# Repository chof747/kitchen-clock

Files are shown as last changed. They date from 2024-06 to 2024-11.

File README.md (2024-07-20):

# Kitchen Clock Project

This project is building a kitchen glock with the following functions:

- Servo driven largely visible glock gauge
- Alarm functions that can be sequenced easily
- Temperature control of a stove or oven
- Integration into home automation systems with HA and/or MQTT
- Ringing alarm function

the project will contain all the necessary electrical and housing components.

## PCB

**v1.0**: Initial version of PCB sent to production on 22.07.2024

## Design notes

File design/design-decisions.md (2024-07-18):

# Design Decisions for Kitchen Clock

## Using USB CDC Mode to upload firmware

I decided to skip the standard ESP serial programmer and use USB JTAG/CDC mode for programming and communicating with the microcontroller on board. 

A breakout of RX/TX, GPIO0 and GND is still provded as a fallback if USB does not work.

Programming the firmware can work as described here:
[USB Settings for Logging with the ESP32-S3 in PlatformIO](https://thingpulse.com/usb-settings-for-logging-with-the-esp32-s3-in-platformio/)

**Note:** It can be possible to put the ESP32 into boot mode before it is able to be programmed. I decided not to add a specified Boot button on the board but one can use the breakout of RX/TX/GPI0 instead

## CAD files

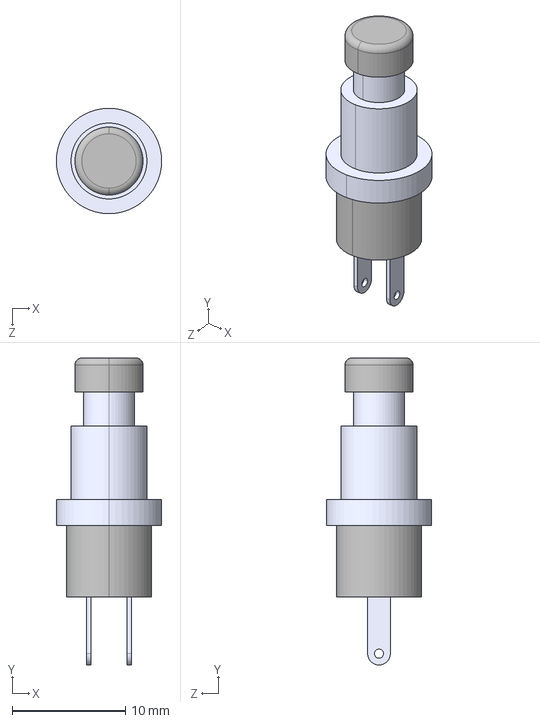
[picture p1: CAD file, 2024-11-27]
3dmodel/resources/button.STEP
9.30 x 27.1 x 9.30 mm

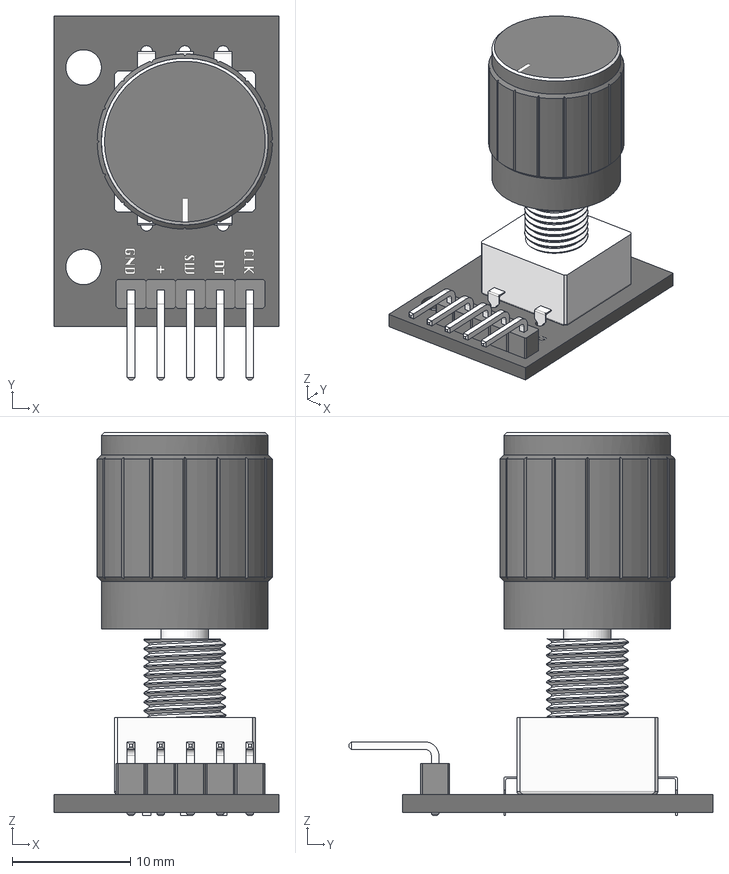
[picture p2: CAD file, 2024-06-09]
3dmodel/resources/Rotary Encoder - KY-040.step
19.0 x 30.8 x 32.4 mm

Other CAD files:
3dmodel/assemblies/clock-assembly.FCStd
3dmodel/assemblies/component-assembly.FCStd
3dmodel/components/base.FCStd
3dmodel/parameter.FCStd
3dmodel/components/socket.FCStd
3dmodel/assemblies/controls.FCStd
3dmodel/components/dial.FCStd
3dmodel/assemblies/base-pcb.FCStd
3dmodel/components/front.FCStd
3dmodel/components/rot-enc-knob.FCStd
3dmodel/components/tftdisplay.FCStd
3dmodel/components/servo-horn.FCStd
3dmodel/components/scafold.FCStd
3dmodel/components/button.FCStd
3dmodel/components/gauge.FCStd
3dmodel/components/pcb.FCStd
3dmodel/components/1.8_inches_128x160_RGB_TFT_LCD v3.step
3dmodel/components/display-bracket.FCStd
3dmodel/components/knob.FCStd
3dmodel/resources/M7 × 0.75 NUT.STEP

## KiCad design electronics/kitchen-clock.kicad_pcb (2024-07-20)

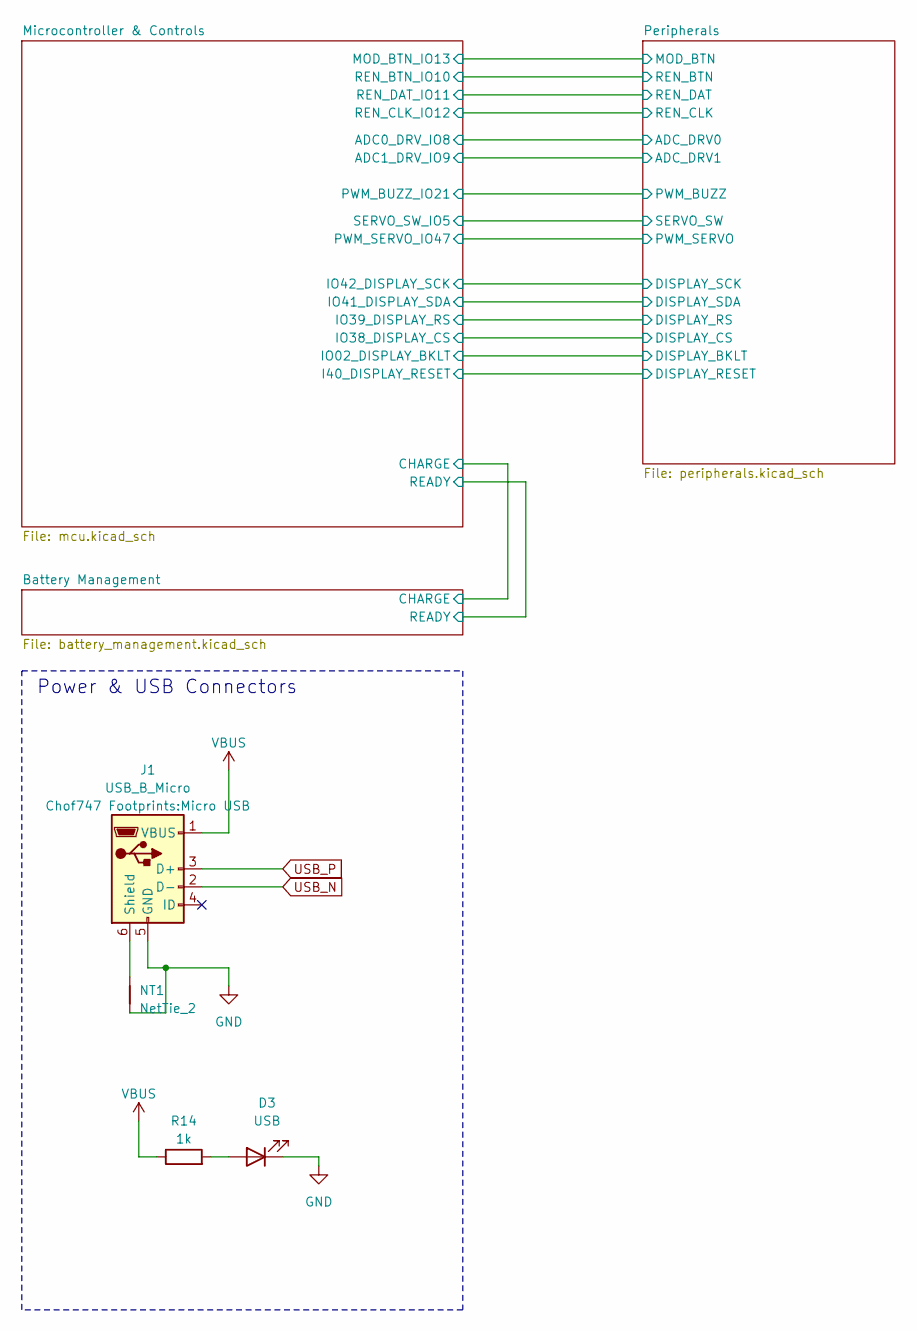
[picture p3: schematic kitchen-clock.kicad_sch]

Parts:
D3: USB; LED_0603_1608Metric_Pad1.05x0.95mm_HandSolder
J1: USB_B_Micro; Micro USB
NT1: NetTie_2; NetTie-2_SMD_Pad0.5mm
R14: 1k; R_0603_1608Metric_Pad0.98x0.95mm_HandSolder

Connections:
GND: D3.1 (K), J1.5 (GND), NT1.1; also elsewhere on the board
unnamed: D3.2 (A), R14.2
unnamed: J1.6 (Shield), NT1.2
USB_N: J1.2 (D-); also elsewhere on the board
USB_P: J1.3 (D+); also elsewhere on the board
VBUS: J1.1 (VBUS), R14.1; also elsewhere on the board

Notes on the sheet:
Power & USB Connectors

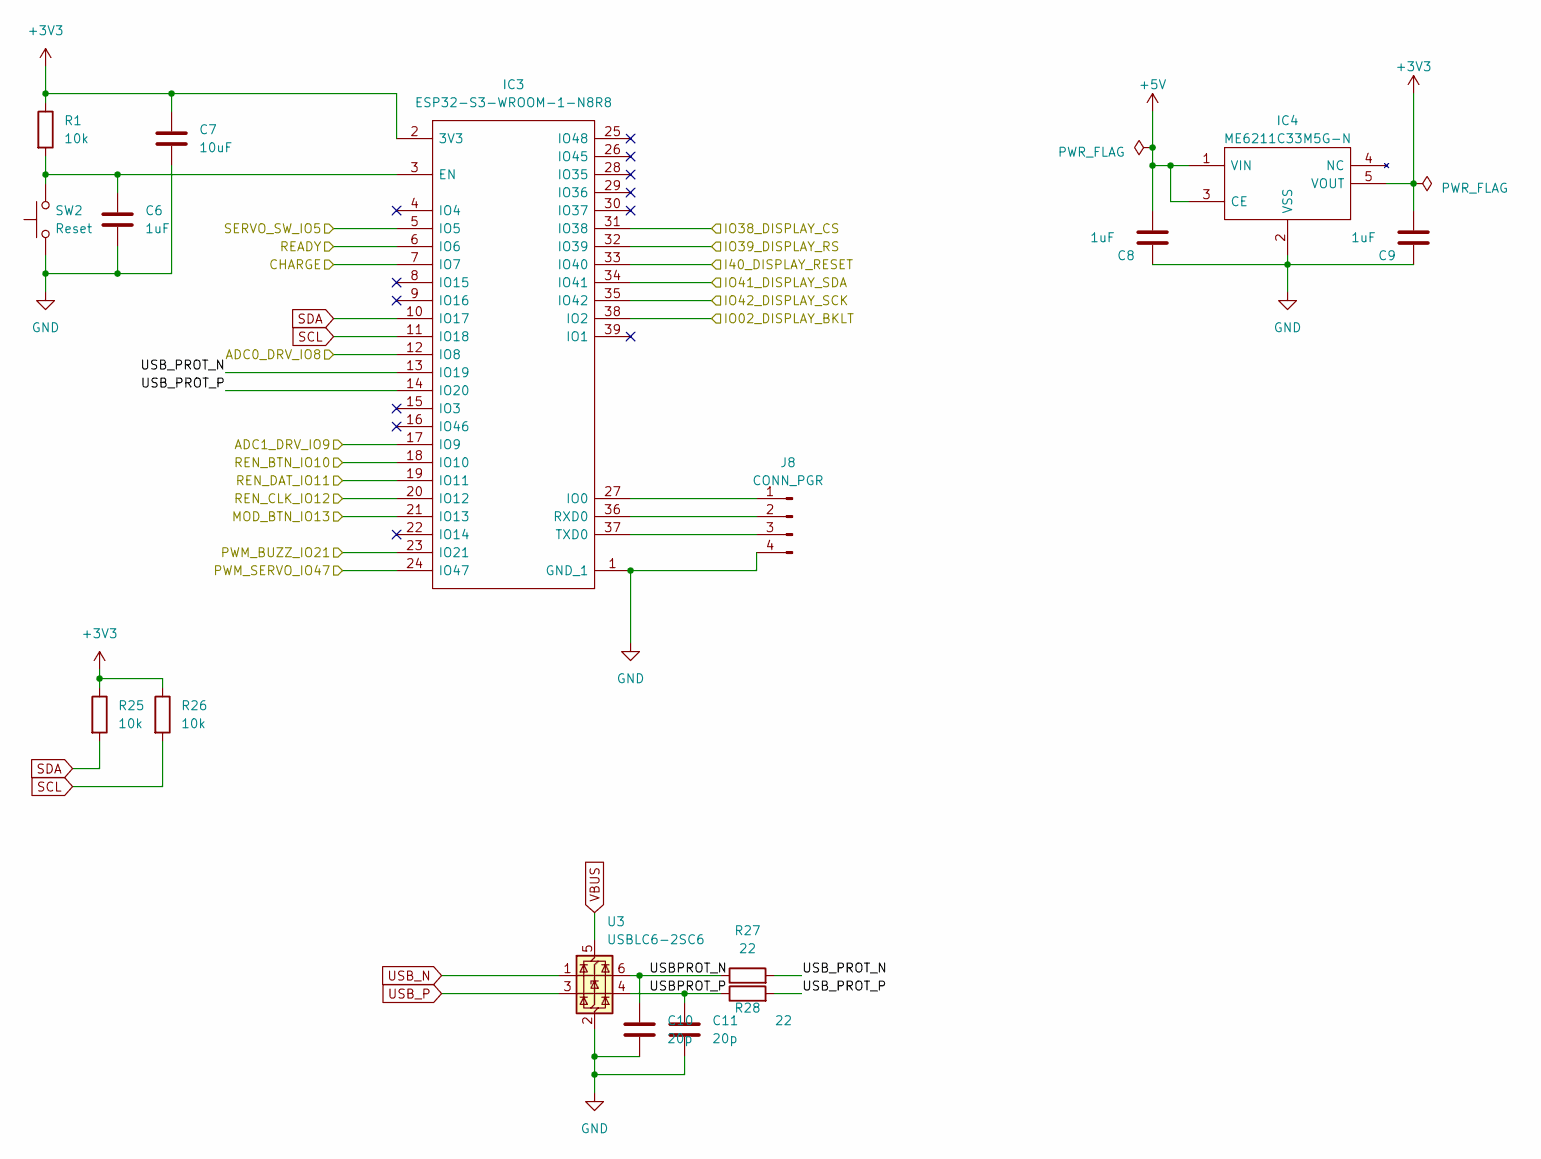
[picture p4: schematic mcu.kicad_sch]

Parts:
C6, C8, C9: 1uF; C_0603_1608Metric_Pad1.08x0.95mm_HandSolder
C7: 10uF; C_0603_1608Metric_Pad1.08x0.95mm_HandSolder
C10, C11: 20p; C_0603_1608Metric_Pad1.08x0.95mm_HandSolder
IC3: ESP32-S3-WROOM-1-N8R8; ESP32S3WROOM1N8R8; Manufacturer_Part_Number ESP32-S3-WROOM-1-N8R8; Mouser Part Number 356-EP32S3WROOM1N8R8
IC4: ME6211C33M5G-N; SOT95P270X145-5N; Manufacturer_Part_Number ME6211C33M5G-N
J8: CONN_PGR; PinSocket_1x04_P2.54mm_Vertical
R1, R25, R26: 10k; R_0603_1608Metric_Pad0.98x0.95mm_HandSolder
R27, R28: 22; R_0603_1608Metric_Pad0.98x0.95mm_HandSolder
SW2: Reset; 1TS003B-2500-3500A-CT (SMD Right Angle Tactile Switch)
U3: USBLC6-2SC6; SOT-23-6

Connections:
+3V3: C7.1, C9.1, IC3.2 (3V3), IC4.5 (VOUT), R1.1, R25.1, R26.1; also elsewhere on the board
+5V: C8.1, IC4.1 (VIN), IC4.3 (CE); also elsewhere on the board
/Battery Management/CHARGE: IC3.7 (IO7); also elsewhere on the board
/Battery Management/READY: IC3.6 (IO6); also elsewhere on the board
/Microcontroller & Controls/ADC0_DRV_IO8: IC3.12 (IO8); also elsewhere on the board
/Microcontroller & Controls/ADC1_DRV_IO9: IC3.17 (IO9); also elsewhere on the board
/Microcontroller & Controls/I40_DISPLAY_RESET: IC3.33 (IO40); also elsewhere on the board
/Microcontroller & Controls/IO02_DISPLAY_BKLT: IC3.38 (IO2); also elsewhere on the board
/Microcontroller & Controls/IO38_DISPLAY_CS: IC3.31 (IO38); also elsewhere on the board
/Microcontroller & Controls/IO39_DISPLAY_RS: IC3.32 (IO39); also elsewhere on the board
/Microcontroller & Controls/IO41_DISPLAY_SDA: IC3.34 (IO41); also elsewhere on the board
/Microcontroller & Controls/IO42_DISPLAY_SCK: IC3.35 (IO42); also elsewhere on the board
/Microcontroller & Controls/MOD_BTN_IO13: IC3.21 (IO13); also elsewhere on the board
/Microcontroller & Controls/PWM_BUZZ_IO21: IC3.23 (IO21); also elsewhere on the board
/Microcontroller & Controls/PWM_SERVO_IO47: IC3.24 (IO47); also elsewhere on the board
/Microcontroller & Controls/REN_BTN_IO10: IC3.18 (IO10); also elsewhere on the board
/Microcontroller & Controls/REN_CLK_IO12: IC3.20 (IO12); also elsewhere on the board
/Microcontroller & Controls/REN_DAT_IO11: IC3.19 (IO11); also elsewhere on the board
/Microcontroller & Controls/SERVO_SW_IO5: IC3.5 (IO5); also elsewhere on the board
/Microcontroller & Controls/USBPROT_N: C10.1, R27.1, U3.6 (I/O1)
/Microcontroller & Controls/USBPROT_P: C11.1, R28.1, U3.4 (I/O2)
/Microcontroller & Controls/USB_PROT_N: IC3.13 (IO19), R27.2
/Microcontroller & Controls/USB_PROT_P: IC3.14 (IO20), R28.2
GND: C6.2, C7.2, C8.2, C9.2, C10.2, C11.2, IC3.1 (GND_1), IC4.2 (VSS), J8.4, SW2.1, U3.2 (GND); also elsewhere on the board
unnamed: C6.1, IC3.3 (EN), R1.2, SW2.2
unnamed: IC3.27 (IO0), J8.1
unnamed: IC3.36 (RXD0), J8.2
unnamed: IC3.37 (TXD0), J8.3
SCL: IC3.11 (IO18), R26.2; also elsewhere on the board
SDA: IC3.10 (IO17), R25.2; also elsewhere on the board
USB_N: U3.1 (I/O1); also elsewhere on the board
USB_P: U3.3 (I/O2); also elsewhere on the board
VBUS: U3.5 (VBUS); also elsewhere on the board

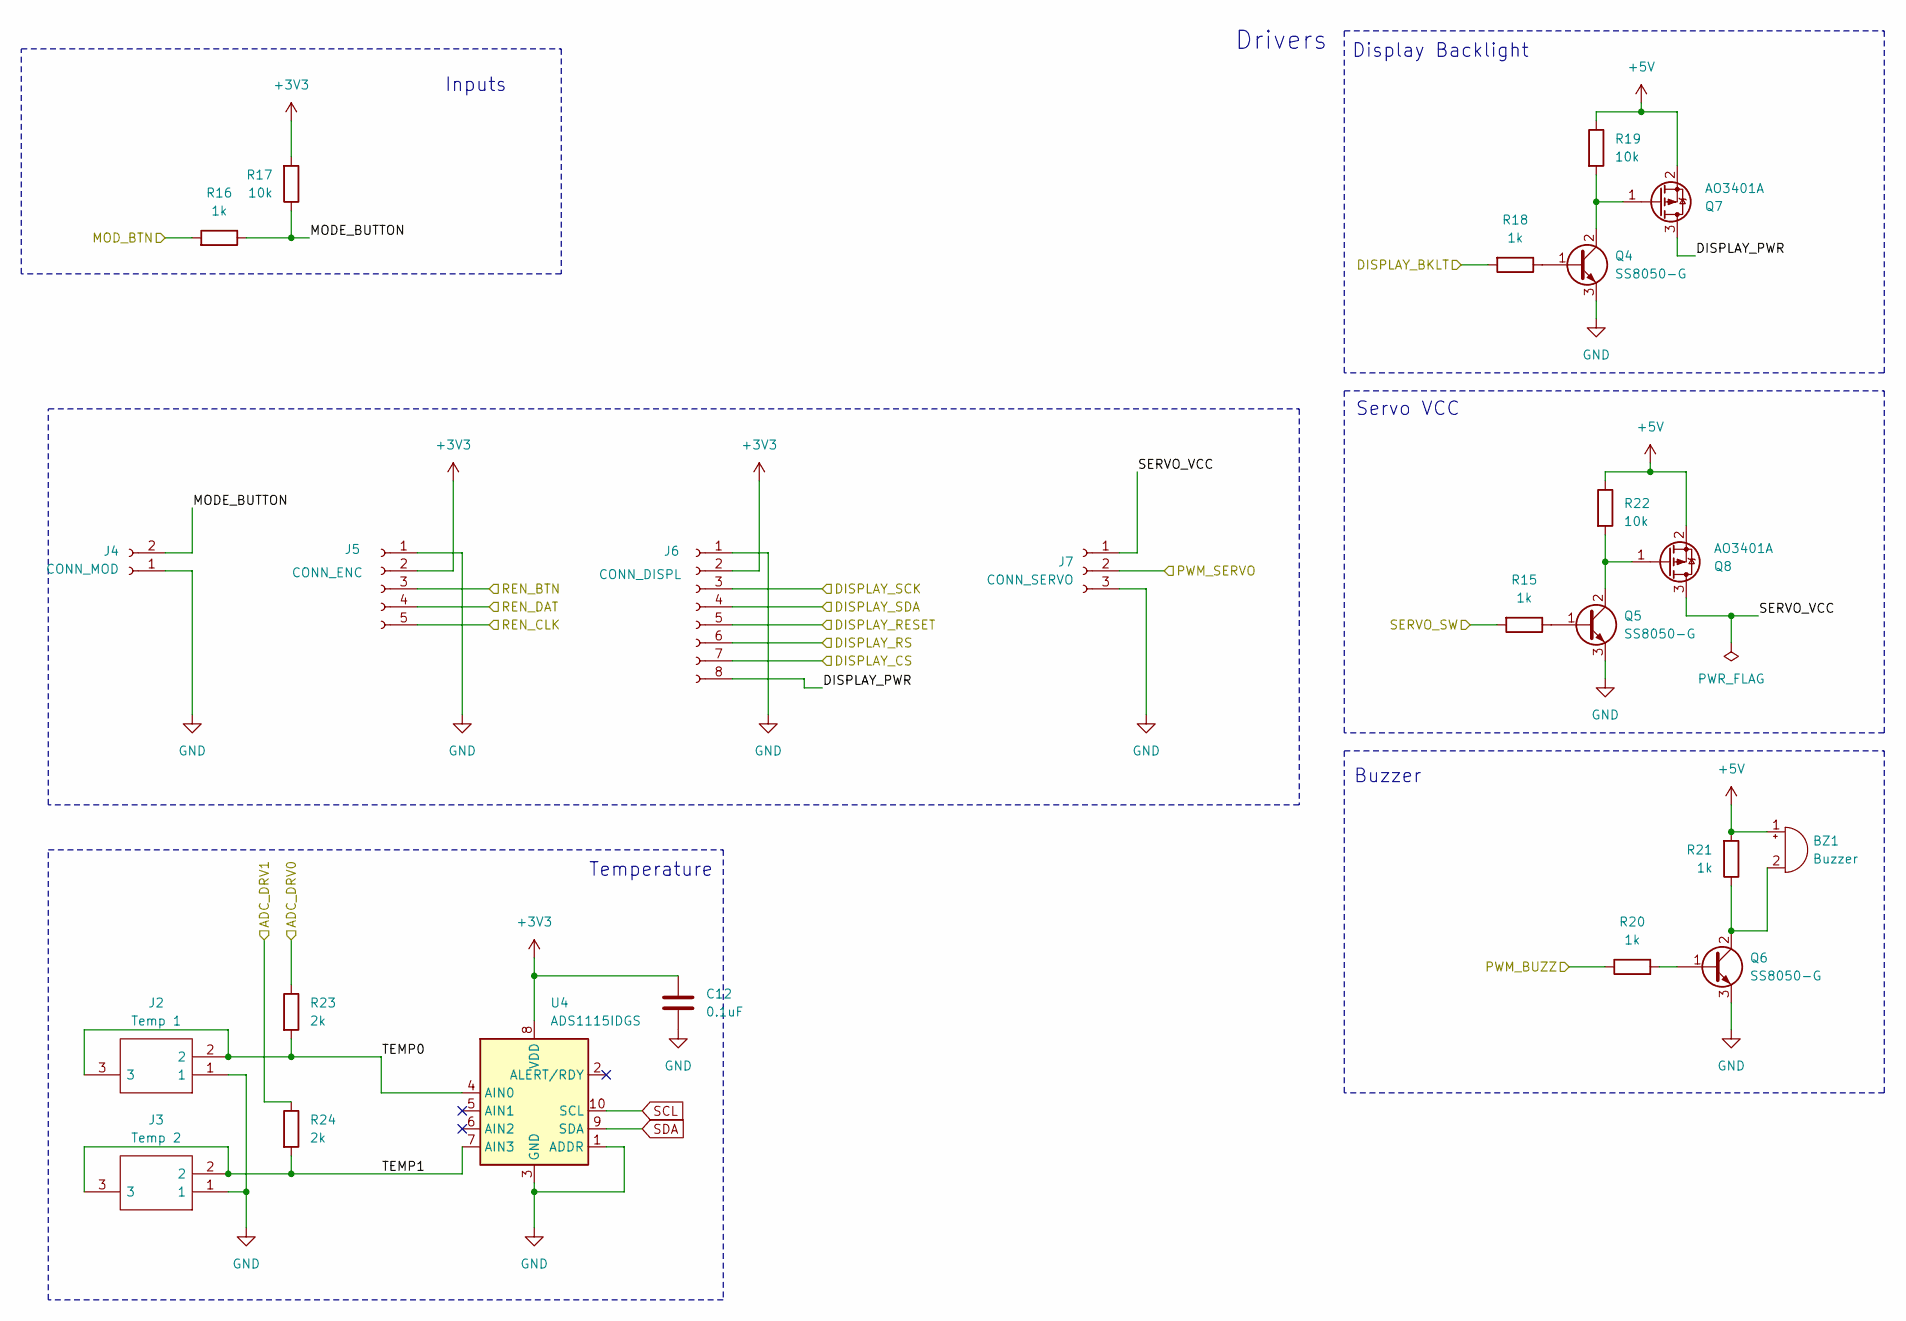
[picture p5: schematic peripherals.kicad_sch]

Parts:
BZ1: Buzzer; PS1240P02BT
C12: 0.1uF; C_0603_1608Metric_Pad1.08x0.95mm_HandSolder
J2: Temp 1; MJ2509N; Manufacturer_Part_Number MJ-2509N; Mouser Part Number 490-MJ-2509N
J3: Temp 2; MJ2509N; Manufacturer_Part_Number MJ-2509N; Mouser Part Number 490-MJ-2509N
J4: CONN_MOD; PinSocket_1x02_P2.54mm_Vertical
J5: CONN_ENC; PinSocket_1x05_P2.54mm_Vertical
J6: CONN_DISPL; PinSocket_1x08_P2.54mm_Vertical
J7: CONN_SERVO; PinSocket_1x03_P2.54mm_Vertical
Q4, Q5, Q6: SS8050-G; SOT-23
Q7, Q8: AO3401A; SOT-23
R15, R16, R18, R20, R21: 1k; R_0603_1608Metric_Pad0.98x0.95mm_HandSolder
R17, R19, R22: 10k; R_0603_1608Metric_Pad0.98x0.95mm_HandSolder
R23, R24: 2k; R_0603_1608Metric_Pad0.98x0.95mm_HandSolder
U4: ADS1115IDGS; TSSOP-10_3x3mm_P0.5mm

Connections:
+3V3: C12.1, J5.2, J6.2, R17.2, U4.8 (VDD); also elsewhere on the board
+5V: BZ1.1 (+), Q7.2 (S), Q8.2 (S), R19.1, R21.2, R22.1; also elsewhere on the board
/Microcontroller & Controls/ADC0_DRV_IO8: R23.1; also elsewhere on the board
/Microcontroller & Controls/ADC1_DRV_IO9: R24.1; also elsewhere on the board
/Microcontroller & Controls/I40_DISPLAY_RESET: J6.5; also elsewhere on the board
/Microcontroller & Controls/IO02_DISPLAY_BKLT: R18.2; also elsewhere on the board
/Microcontroller & Controls/IO38_DISPLAY_CS: J6.7; also elsewhere on the board
/Microcontroller & Controls/IO39_DISPLAY_RS: J6.6; also elsewhere on the board
/Microcontroller & Controls/IO41_DISPLAY_SDA: J6.4; also elsewhere on the board
/Microcontroller & Controls/IO42_DISPLAY_SCK: J6.3; also elsewhere on the board
/Microcontroller & Controls/MOD_BTN_IO13: R16.2; also elsewhere on the board
/Microcontroller & Controls/PWM_BUZZ_IO21: R20.1; also elsewhere on the board
/Microcontroller & Controls/PWM_SERVO_IO47: J7.2; also elsewhere on the board
/Microcontroller & Controls/REN_BTN_IO10: J5.3; also elsewhere on the board
/Microcontroller & Controls/REN_CLK_IO12: J5.5; also elsewhere on the board
/Microcontroller & Controls/REN_DAT_IO11: J5.4; also elsewhere on the board
/Microcontroller & Controls/SERVO_SW_IO5: R15.2; also elsewhere on the board
/Peripherals/DISPLAY_PWR: J6.8, Q7.3 (D)
/Peripherals/MODE_BUTTON: J4.2, R16.1, R17.1
/Peripherals/SERVO_VCC: J7.1, Q8.3 (D)
/Peripherals/TEMP0: J2.2, J2.3, R23.2, U4.4 (AIN0)
/Peripherals/TEMP1: J3.2, J3.3, R24.2, U4.7 (AIN3)
GND: C12.2, J2.1, J3.1, J4.1, J5.1, J6.1, J7.3, Q4.3 (E), Q5.3 (E), Q6.3 (E), U4.1 (ADDR), U4.3 (GND); also elsewhere on the board
unnamed: BZ1.2 (-), Q6.2 (C), R21.1
unnamed: Q4.1 (B), R18.1
unnamed: Q4.2 (C), Q7.1 (G), R19.2
unnamed: Q5.1 (B), R15.1
unnamed: Q5.2 (C), Q8.1 (G), R22.2
unnamed: Q6.1 (B), R20.2
SCL: U4.10 (SCL); also elsewhere on the board
SDA: U4.9 (SDA); also elsewhere on the board

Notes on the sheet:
Temperature
Servo VCC
Inputs
Drivers
Buzzer
Display Backlight

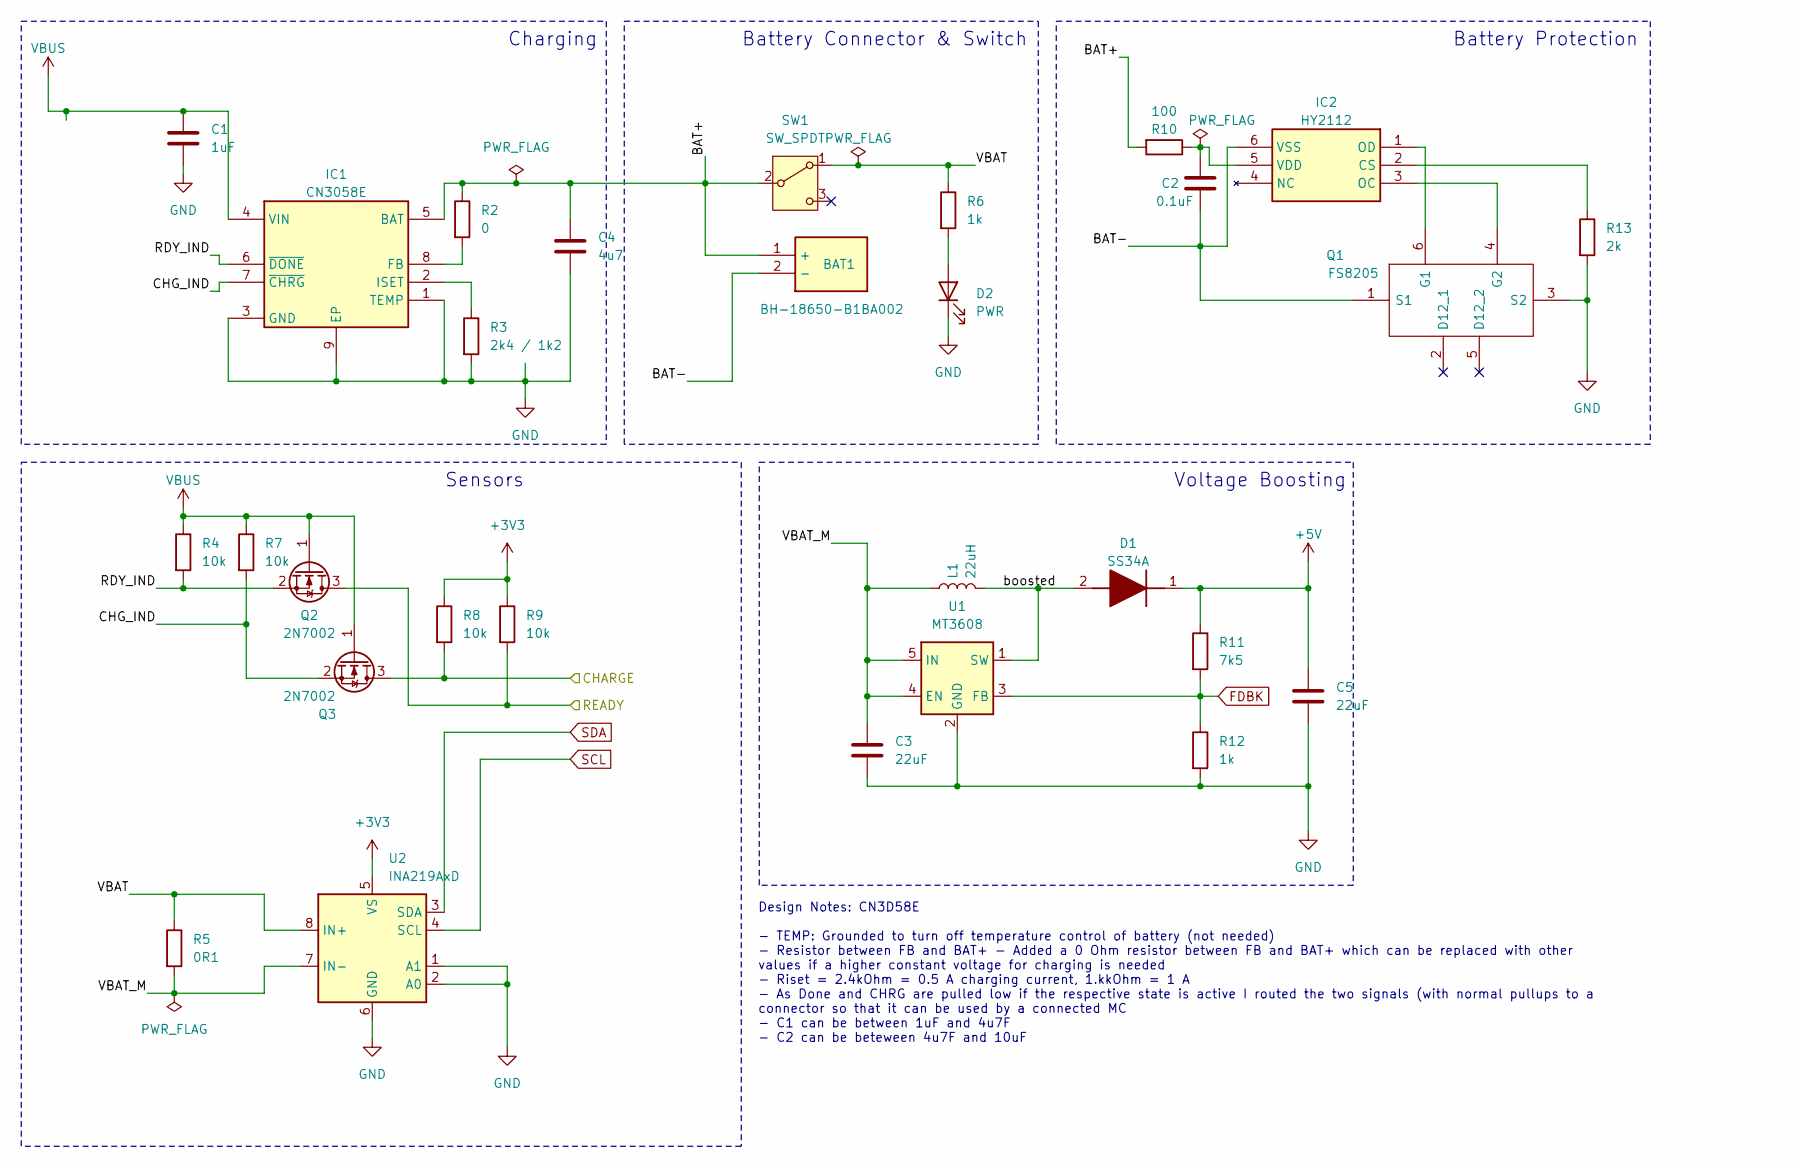
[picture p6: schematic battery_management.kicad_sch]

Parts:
BAT1: BH-18650-B1BA002; BH18650B1BA002; Manufacturer_Part_Number BH-18650-B1BA002
C1: 1uF; C_0603_1608Metric_Pad1.08x0.95mm_HandSolder
C2: 0.1uF; C_0603_1608Metric_Pad1.08x0.95mm_HandSolder
C3, C5: 22uF; C_1206_3216Metric_Pad1.33x1.80mm_HandSolder
C4: 4u7; C_0603_1608Metric_Pad1.08x0.95mm_HandSolder
D1: SS34A; DIOM5026X262N; Manufacturer_Part_Number SS34A
D2: PWR; LED_0603_1608Metric_Pad1.05x0.95mm_HandSolder
IC1: CN3058E; SOIC127P600X175-9N; Manufacturer_Part_Number CN3058E
IC2: HY2112; SOT95P280X145-6N; Manufacturer_Part_Number HY2112
L1: 22uH; SMD0740
Q1: FS8205; Manufacturer_Part_Number FS8205
Q2, Q3: 2N7002; SOT-23
R2: 0; R_0603_1608Metric_Pad0.98x0.95mm_HandSolder
R3: 2k4 / 1k2; R_0603_1608Metric_Pad0.98x0.95mm_HandSolder
R4, R7, R8, R9: 10k; R_0603_1608Metric_Pad0.98x0.95mm_HandSolder
R5: 0R1; R_2512_6332Metric_Pad1.40x3.35mm_HandSolder
R6, R12: 1k; R_0603_1608Metric_Pad0.98x0.95mm_HandSolder
R10: 100; R_0603_1608Metric_Pad0.98x0.95mm_HandSolder
R11: 7k5; R_0603_1608Metric_Pad0.98x0.95mm_HandSolder
R13: 2k; R_0603_1608Metric_Pad0.98x0.95mm_HandSolder
SW1: SW_SPDT; Slide-switch-SS-12D11L7
U1: MT3608; SOT-23-6
U2: INA219AxD; SOIC-8_3.9x4.9mm_P1.27mm

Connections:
+3V3: R8.1, R9.1, U2.5 (VS); also elsewhere on the board
+5V: C5.1, D1.1 (K), R11.1; also elsewhere on the board
/Battery Management/BAT+: BAT1.1 (+), C4.1, IC1.5 (BAT), R2.1, R10.2, SW1.2 (B)
/Battery Management/BAT-: BAT1.2 (-), C2.2, IC2.6 (VSS), Q1.1 (S1)
/Battery Management/CHARGE: Q3.3 (D), R8.2; also elsewhere on the board
/Battery Management/CHG_IND: IC1.7 (~CHRG), Q3.2 (S), R7.2
/Battery Management/RDY_IND: IC1.6 (~DONE), Q2.2 (S), R4.2
/Battery Management/READY: Q2.3 (D), R9.2; also elsewhere on the board
/Battery Management/VBAT: R5.1, R6.1, SW1.1 (A), U2.8 (IN+)
/Battery Management/VBAT_M: C3.1, L1.1, R5.2, U1.4 (EN), U1.5 (IN), U2.7 (IN-)
/Battery Management/boosted: D1.2 (A), L1.2, U1.1 (SW)
FDBK: R11.2, R12.1, U1.3 (FB)
GND: C1.2, C3.2, C4.2, C5.2, D2.1 (K), IC1.1 (TEMP), IC1.3 (GND), IC1.9 (EP), Q1.3 (S2), R3.2, R12.2, R13.2, U1.2 (GND), U2.1 (A1), U2.2 (A0), U2.6 (GND); also elsewhere on the board
unnamed: D2.2 (A), R6.2
unnamed: IC1.8 (FB), R2.2
unnamed: IC1.2 (ISET), R3.1
unnamed: IC2.2 (CS), R13.1
unnamed: IC2.3 (OC), Q1.4 (G2)
unnamed: IC2.1 (OD), Q1.6 (G1)
unnamed: C2.1, IC2.5 (VDD), R10.1
SCL: U2.4 (SCL); also elsewhere on the board
SDA: U2.3 (SDA); also elsewhere on the board
VBUS: C1.1, IC1.4 (VIN), Q2.1 (G), Q3.1 (G), R4.1, R7.1; also elsewhere on the board

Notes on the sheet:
Design Notes: CN3D58E - TEMP: Grounded to turn off temperature control of battery (not needed) - Resistor between FB and BAT+ - Added a 0 Ohm resistor between FB and BAT+ which can be replaced with other values if a higher constant voltage for charging is needed - Riset = 2.4kOhm = 0.5 A charging c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
Battery Protection
Battery Connector & Switch
Voltage Boosting
Charging
Sensors

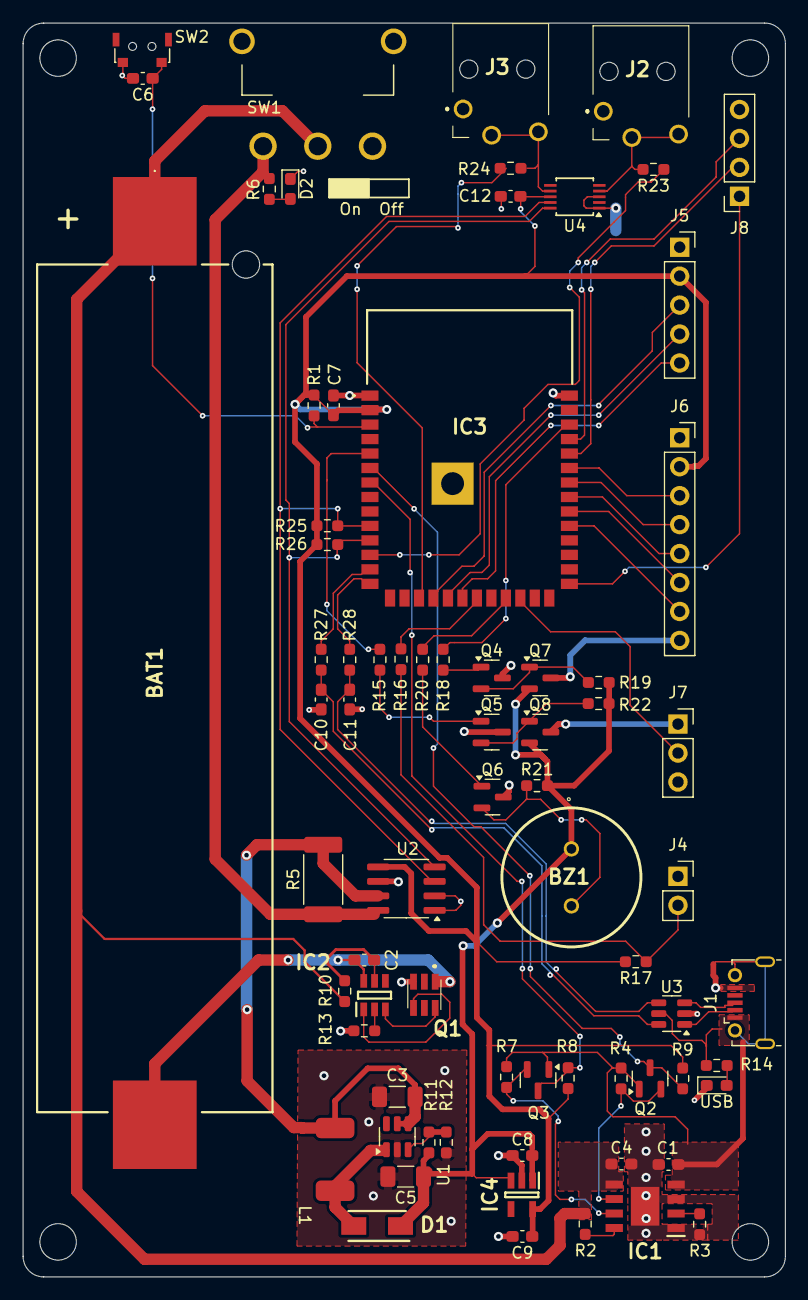
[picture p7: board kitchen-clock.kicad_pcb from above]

Board: 2 copper layers, 66.9 x 110.0 mm, 73 parts (0 on the bottom side), 61 nets.

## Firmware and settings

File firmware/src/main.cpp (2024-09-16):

#include "config.h"

#include <Arduino.h>
#include "logengine.h"
#include "logengine/serial.h"
#include "modfirmware.h"
#include "wlan.h"
#include "mqtt.h"
#include "gpiobutton.h"
#include "roteryencoder.h"
#include "servo.h"
#include "multitimer.h"
#include "tftdisplay.h"
#include "powermanagement.h"
#include "statuscontroller.h"
#include "regions/statusregion.h"
#include <Wire.h>
#include <SPI.h>

#define RDY_IND 6
#define CHG_IND 7


#define LOGTAG "main"

ModFirmWare::LogEngine *logger = ModFirmWare::LogEngine::getInstance();
ModFirmWare::LogEngineSerial logger_serial(MODFIRMWARE_LOG_LEVEL, ModFirmWare::usbCDCHelper(9600));
ModFirmWare::WLan wifi("kitchen-clock", "KitchenClock");
ModFirmWare::Mqtt mqttClient;

ModFirmWare::GPIOButton modeButton(MODE_BTN, INPUT_PULLUP, true);
ModFirmWare::GPIOButton rotaryButton(REN_BTN, INPUT_PULLUP, true);
ModFirmWare::PowerManagement powerMgmt(CHG_IND, RDY_IND);
ModFirmWare::RotaryEncoder encoder(REN_CLK, REN_DAT);
ModFirmWare::Servo clock_servo(SERVO_PWM, SERVO_DRV, 
                               SERVO_PWM_CHANNEL, SERVO_PWM_RESOLUTION, SERVO_FREQ,
                               SERVO_MIN_PULSE, SERVO_MAX_PULSE);
ModFirmWare::TFTDisplay display(DISPLAY_CS,DISPLAY_RS,DISPLAY_RST);

ModFirmWare::MultiTimer mtimer(5 IN_SECONDS);

ModFirmWare::Application app("KitchenClock");

KitchenClock::StatusController statuscontroller(&powerMgmt, &wifi, &mqttClient, &display, {0, 0, 160, 16});

time_t lastAction = 0;
time_t reactivaTimerAt = 0;
long servoPosition = 0;

void resetWifiSettings(const char *topic, const char *payload)
//******************************************************************************
{
  if (0 == strcmp("reset", payload))
  {
    wifi.resetWifiSettings();
  }
}

void modeButtonPress(uint16_t state, ModFirmWare::Buttons::click_t clicktype)
{
  int d = digitalRead(DISPLAY_BKLT);
  d = (LOW == d) ? HIGH : LOW;
  digitalWrite(DISPLAY_BKLT, d);
}

void setup()
{
  //setup peripheral interfaces;
  Wire.begin(I2C_SDA, I2C_SCL);
  SPI.begin(DISPLAY_SCK, -1, DISPLAY_SDA);

  // put your setup code here, to run once:
  logger->addStrategy(&logger_serial);  

  app.setDeviceName("test_esp32");
  app.addComponent(&wifi);


  app.addComponent(&mqttClient);
  mqttClient.setClient(wifi.getClient());
  wifi.addConfigurator(&mqttClient);

  app.addComponent(&powerMgmt);

  app.addComponent(&modeButton);
  modeButton.setButtonPressedCallBack(modeButtonPress);
/*
  app.addComponent(&encoder);
  app.addComponent(&rotaryButton);
*/
  
/*
  app.addComponent(&clock_servo);
  app.addComponent(&mtimer);
*/
  delay(2000);

  pinMode(DISPLAY_BKLT, OUTPUT);
  digitalWrite(DISPLAY_BKLT, LOW);

  logger->debug(LOGTAG, "Starting setup");
  app.setup();

  statuscontroller.activate();
  mqttClient.registerCommand("resetwifi", resetWifiSettings);

  logger->info(LOGTAG, "Setup Done!");

  mtimer.start();
}

void loop()
{
  statuscontroller.loop();
  app.loop();
  // logger->info(LOGTAG,"Hello World!");
}

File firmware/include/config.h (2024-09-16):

#ifndef CONFIG_H
#define CONFIG_H

//Board Pin Definitions

#define RDY_IND       6  // charging indicator battery charger
#define CHG_IND       7  // ready indicator battery charger

#define SERVO_DRV     5  // Pin driving Servo high-side switch
#define SERVO_PWM    47  // PWM pin for servo control

#define ADC_00_DRV    8  // Pin driving 3v3 line for ADC 0 (to prevent termister overheat)
#define ADC_01_DRV    9  // Pin driving 3v3 line for ADC 1 (to prevent termister overheat)

#define MODE_BTN     13  // Mode button pin
#define REN_BTN      10  // Rotary ENcoder click button pin
#define REN_DAT      11  // Rotery ENcoder data line
#define REN_CLK      12  // Rotery ENcoder clock line

#define BUZZ_PWM     21  // PWM pin for Buzzer control

#define DISPLAY_CS   38  // TFT display chip select
#define DISPLAY_RS   39  // TFT display register select
#define DISPLAY_RST  40  // TFT display reset
#define DISPLAY_SDA  41  // TFT display data line
#define DISPLAY_SCK  42  // TFT display clock line
#define DISPLAY_BKLT  2  // Pin driving high-side switch for TFT display backlight

#define I2C_SDA      17  // I2C data line
#define I2C_SCL      18  // I2C clock line

//Other board and peripheral definitions
#define SERVO_PWM_CHANNEL     0  // esp32 internal pwm channel
#define SERVO_PWM_RESOLUTION 10  // pwm resolution in bit
#define SERVO_FREQ           50  // frequency of the pwm channel for the servo in Hz
#define SERVO_MIN_PULSE     500  // minmum pulse width for 0°
#define SERVO_MAX_PULSE    2500  // maximum pulse width for 180°

//Battery Management

// Define the voltage thresholds (in millivolts)
#define FULLY_CHARGED_VOLTAGE 3650 // 3.65V, 100%
#define ALMOST_FULL_VOLTAGE 3500   // 3.50V, 90%
#define HIGH_VOLTAGE 3400          // 3.40V, 70%
#define MEDIUM_VOLTAGE 3300        // 3.30V, 40%
#define LOW_VOLTAGE 3200           // 3.20V, 20%
#define VERY_LOW_VOLTAGE 3000      // 3.00V, 10%
#define MINIMUM_VOLTAGE 2800       // 2.80V, 0%

// Define the percentage values at the thresholds
#define PERCENT_FULL 100
#define PERCENT_ALMOST_FULL 90
#define PERCENT_HIGH 70
#define PERCENT_MEDIUM 40
#define PERCENT_LOW 20
#define PERCENT_VERY_LOW 10
#define PERCENT_MINIMUM 0


#endif //CONFIG_H

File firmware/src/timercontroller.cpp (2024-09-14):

#include "timercontroller.h"
#include "tftdisplay.h"
#include "roteryencoder.h"
#include "gpiobutton.h"
#include "servo.h"

using namespace KitchenClock;

TimerController::TimerController(ModFirmWare::TFTDisplay *display,
                                 ModFirmWare::RotaryEncoder *rotenc,
                                 ModFirmWare::GPIOButton rotencBtn,
                                 ModFirmWare::GPIOButton modeBtn,
                                 ModFirmWare::MultiTimer timer,
                                 ModFirmWare::Servo servo)
//****************************************************************************************
{
}

void TimerController::loop()
//****************************************************************************************
{
}

void TimerController::activate()
//****************************************************************************************
{
}

bool TimerController::onTimerMileStone(const char *caption, time_t atTime)
//****************************************************************************************
{
  return true;
}

bool TimerController::onTimerPeriod(const ModFirmWare::MultiTimer::periodtype_t periodType,
                                    time_t atTime, time_t elapsed, time_t remaining,
                                    time_t toNextMilestone)
//****************************************************************************************
{
  return true;
}

void TimerController::onTimerFinished(time_t atTime)
//****************************************************************************************
{
}

void TimerController::onTimerPause(time_t atTime)
//****************************************************************************************
{
}

void TimerController::onTimerResume(time_t atTime)
//****************************************************************************************
{
}

void TimerController::onTimerStart(time_t atTime)
//****************************************************************************************
{
}

void TimerController::onTimerReset(time_t atTime)
//****************************************************************************************
{
}

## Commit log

2024-04-30 Initial commit with dial and clock
    [dial.FCStd, gauge.FCStd, parameter.FCStd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]
2024-05-15 Further developing of the 3d models: - completed socket, gauge, base and dial - added assembly file - updated documentation
    [base.FCStd, dial.FCStd, gauge.FCStd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]
2024-05-20 Added template for tft display
    [1.8_inches_128x160_RGB_TFT_LCD v3.step]
2024-05-20 Further progress on 3d model: - Finished socket - Added base - Minor changes to dial before first print
    [base.FCStd, dial.FCStd, parameter.FCStd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]
2024-05-20 recreation of real servo Horn
2024-05-20 Changed shape of servo horn to actual shape
    [dial.FCStd, servo_dial.FCStd]
2024-06-08 Next update to 3dmodel
    [base.FCStd, dial.FCStd, servo_dial.FCStd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]
2024-06-08 Added script and hook for stl generatio upon pushing to the main branch
2024-06-08 change stl zip generation and upload
2024-06-09 Added nuts and model for rotary encoder
    [M7 × 0.75 NUT.STEP, Rotary Encoder - KY-040.step, base.FCStd]
2024-06-09 initialized kicad project
    [kitchen-clock.kicad_pcb]
2024-06-09 draft of schematics done
    [battery_management.kicad_sch, kitchen-clock.kicad_sch, mcu.kicad_sch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]
2024-06-16 First draft of schematic and PCB of controller board
    [battery_management.kicad_sch, kitchen-clock.kicad_pcb, kitchen-clock.kicad_sch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]
2024-06-21 changed footprint of reset button
    [kitchen-clock.kicad_pcb]
2024-06-21 added kicad cache directory to .gitignore
2024-06-21 Model update
    [base-pcb.FCStd, base.FCStd, clock-assembly.FCStd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]
2024-06-21 added knob for Rotary Encoder
    [base-pcb.FCStd, base.FCStd, knob.FCStd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]
2024-06-24 performed CRC check and fixed errors
    [battery_management.kicad_sch, kitchen-clock.kicad_pcb]
2024-06-24 further progress on the model
    [base-pcb.FCStd, base.FCStd, knob.FCStd]
2024-07-18 Performed CRC and DRC on board + corrections
    [kitchen-clock.kicad_pcb, peripherals.kicad_sch]
2024-07-20 fixed reference issues with 3d models
    [kitchen-clock.kicad_pcb]
2024-07-20 minor change in project file for kicad
2024-07-20 added pcb v1.0 to README
2024-09-14 Adjustments after first test print of base
    [base-pcb.FCStd, base.FCStd, socket.FCStd]
2024-09-16 Added battery voltage levels
2024-09-21 updated pcb 3d file with correct battery model
    [pcb.FCStd]
2024-09-26 first upload of new component assembly and case
    [base.FCStd, button.FCStd, button.STEP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]
2024-09-26 updates to 3d case model
    [base.FCStd, component-assembly.FCStd, pcb.FCStd]
2024-10-13 new base and scaffold based on assembly
    [base-pcb.FCStd, base.FCStd, button.FCStd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]
2024-10-14 fixed indexing issues with base profile of scaffold
    [scafold.FCStd]
2024-10-14 started working on front component
    [front.FCStd]
2024-10-15 added gauge to assembly and fixed servo real dimensions
    [base.FCStd, component-assembly.FCStd, controls.FCStd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]
2024-10-18 update to freecad 1.0rc2 and changed front config
    [base.FCStd, component-assembly.FCStd, controls.FCStd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]
2024-10-18 corrected unintended void on the lift side of the pcb which distorted the symmetry
    [base.FCStd]
2024-10-18 adjusted assembly
    [base.FCStd, component-assembly.FCStd]
2024-10-20 assembly of components completed
    [component-assembly.FCStd, gauge.FCStd, knob.FCStd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]
2024-10-20 added servo to assembly
    - Corrected Servo file servo-horn
    - Reduced thickness of gauge
    - Added servo to assembly
    [component-assembly.FCStd, gauge.FCStd, servo-horn.FCStd]
2024-10-25 Intermediate commit
    [base.FCStd, button.FCStd, component-assembly.FCStd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]
2024-10-25 Version 1 of front and base done
    [base.FCStd, component-assembly.FCStd, front.FCStd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]
2024-10-26 Added bracket for display and servo
    [component-assembly.FCStd, display-bracket.FCStd, front.FCStd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]
2024-10-28 Added chamfers and filet to front
    [base.FCStd, component-assembly.FCStd, front.FCStd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]
2024-10-28 corrected display pcb overstand to 0
    [base.FCStd, component-assembly.FCStd, display-bracket.FCStd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]
2024-10-31 Recentered screen and assembly
    [base.FCStd, component-assembly.FCStd, display-bracket.FCStd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]
2024-11-27 final modifications for printing
    [base.FCStd, component-assembly.FCStd, dial.FCStd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]
